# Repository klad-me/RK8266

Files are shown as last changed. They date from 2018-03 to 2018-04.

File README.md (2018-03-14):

# RK8266
Эмулятор Радио-86РК на ESP8266

# Железо
<ul>
    <li>ESP8266 (с флэшкой), например ESP-01: эмулирует процессор и переферию РК86, генерирует видеосигнал стандарта PAL, 
	обрабатывает PS/2 клавиатуру.</li>
    <li>74HC00 (4 элемента 2И-НЕ): используется для генерации видео и синхроимульсов (там простая логика, описана в схеме).</li>
</ul>
В каталоге pcb/ESP-01-LUT есть проект для изготовления платы ЛУТом.<br/>
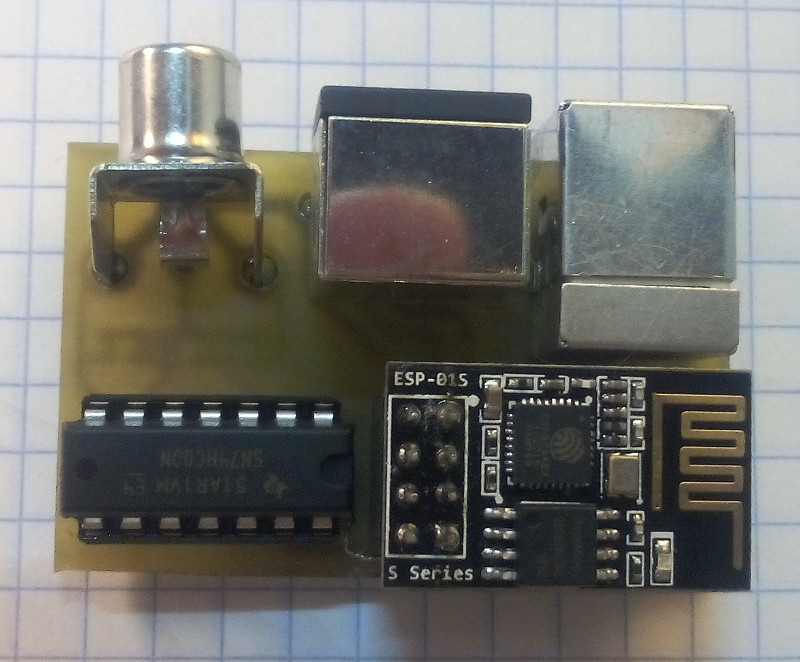
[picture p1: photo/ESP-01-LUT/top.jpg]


# Исходники
Во всех исходниках кодировка КОИ8-Р.<br/>
Проект в стадии разработки.<br/>

# Состав прошивки
Прошивка состоит из 4 частей:
<ul>
    <li>soft/boot-2apps - загрузчик, который переключает между эмулятором и WiFi-прилоежнием.</li>
    <li>soft/EmuAPP - сам эмулятор, работает без SDK полностью из IRAM.</li>
    <li>soft/WiFiAPP - WiFi-приложение для обмена файлами с компьютером.</li>
    <li>soft/WiFiAPP/httpfs - файловая система для HTTP-сервера.</li>
</ul>

# Готовые сборки
Готовые сборки лежат в каталоге builds. Каждый файл имеет имя, соответствующее адресу для прошивки в флэш.<br/>
При прошивке не забывайте правильно указывать размер флэша.<br/>
Пока что все сборки под плату ESP-01-LUT.

# Эмулятор i8080
Используется эмулятор https://github.com/begoon/i8080-core<br/>
При работе ESP8266 на 160МГц и работающем генераторе видеосигнала, частота эмуляции i8080 7.6 .. 8.2 МГц !<br/>

# Переферия
На данный момент реализовано:
<ul>
<li>Процессор (ВМ80) - частота ограничена на 1.78МГц (в будущем, возможно будет турбо-кнопка)</li>
<li>Экран (ВГ75, ИК57) - вывод композитного PAL-сигнала (пока только текст)</li>
<li>Клавиатура (ВВ55) - PS/2 клавиатура с автоматической перекодировкой русских букв и спец.символов</li>
</ul>

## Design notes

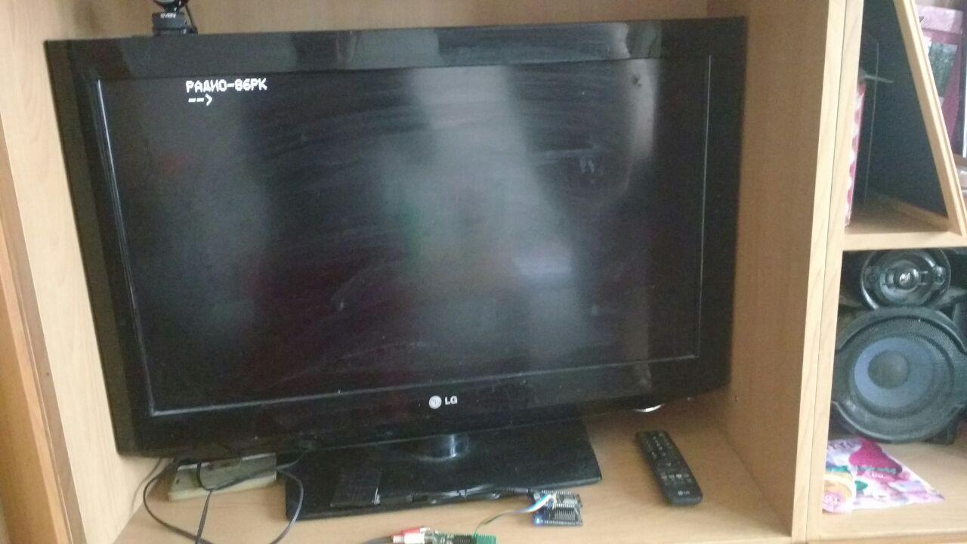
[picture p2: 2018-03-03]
photo/tv.jpg

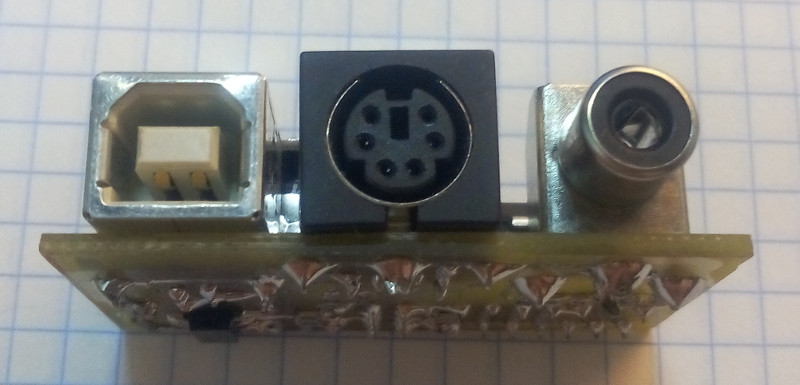
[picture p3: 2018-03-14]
photo/ESP-01-LUT/conn.jpg

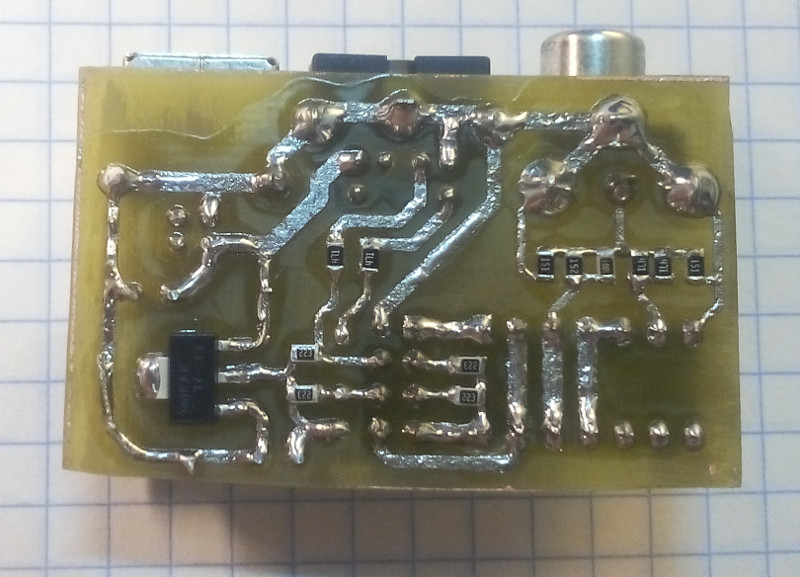
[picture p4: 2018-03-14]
photo/ESP-01-LUT/bottom.jpg

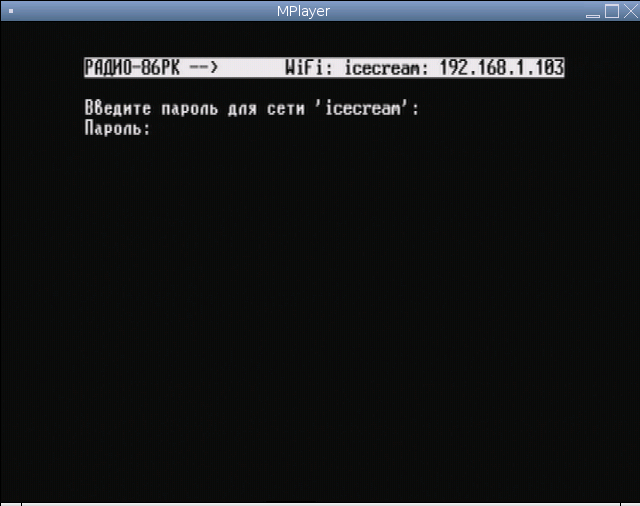
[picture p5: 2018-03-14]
screenshots/rk8266_6.png

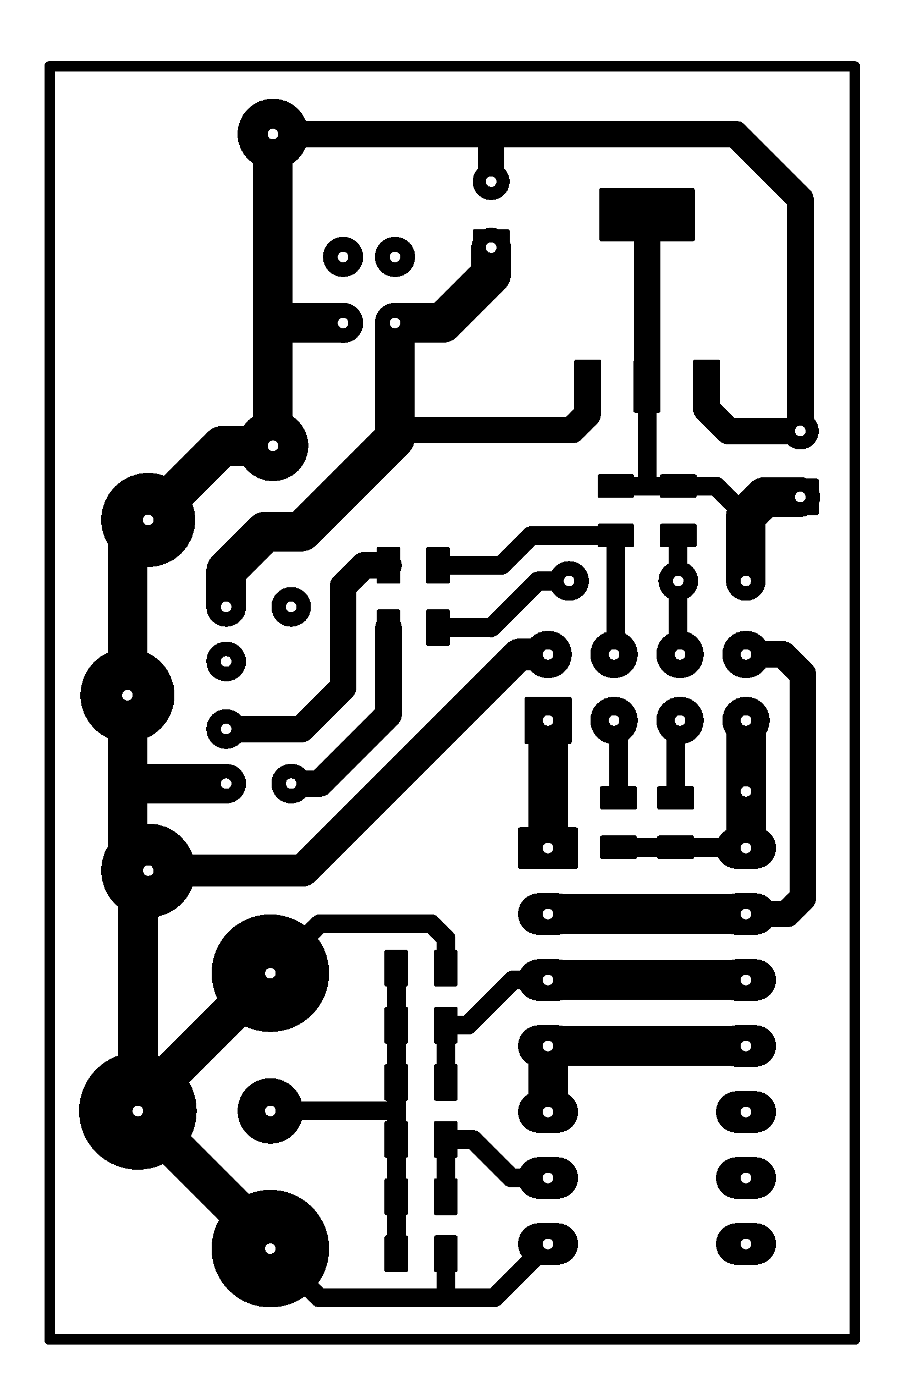
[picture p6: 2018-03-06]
pcb/ESP-01-LUT/pcb/pcb_back.png

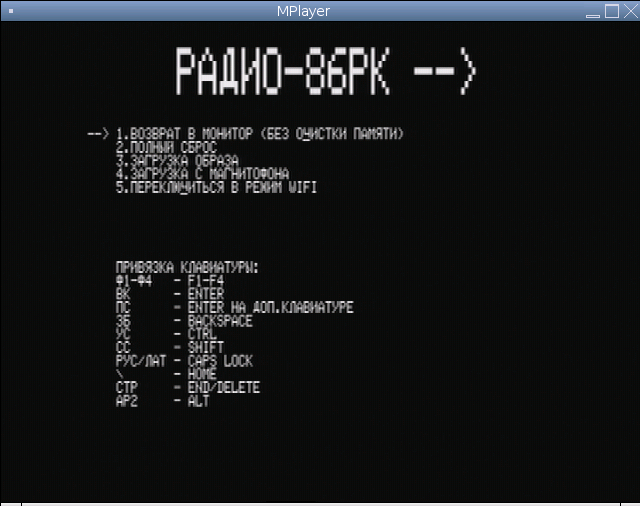
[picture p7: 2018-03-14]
screenshots/rk8266_2.png

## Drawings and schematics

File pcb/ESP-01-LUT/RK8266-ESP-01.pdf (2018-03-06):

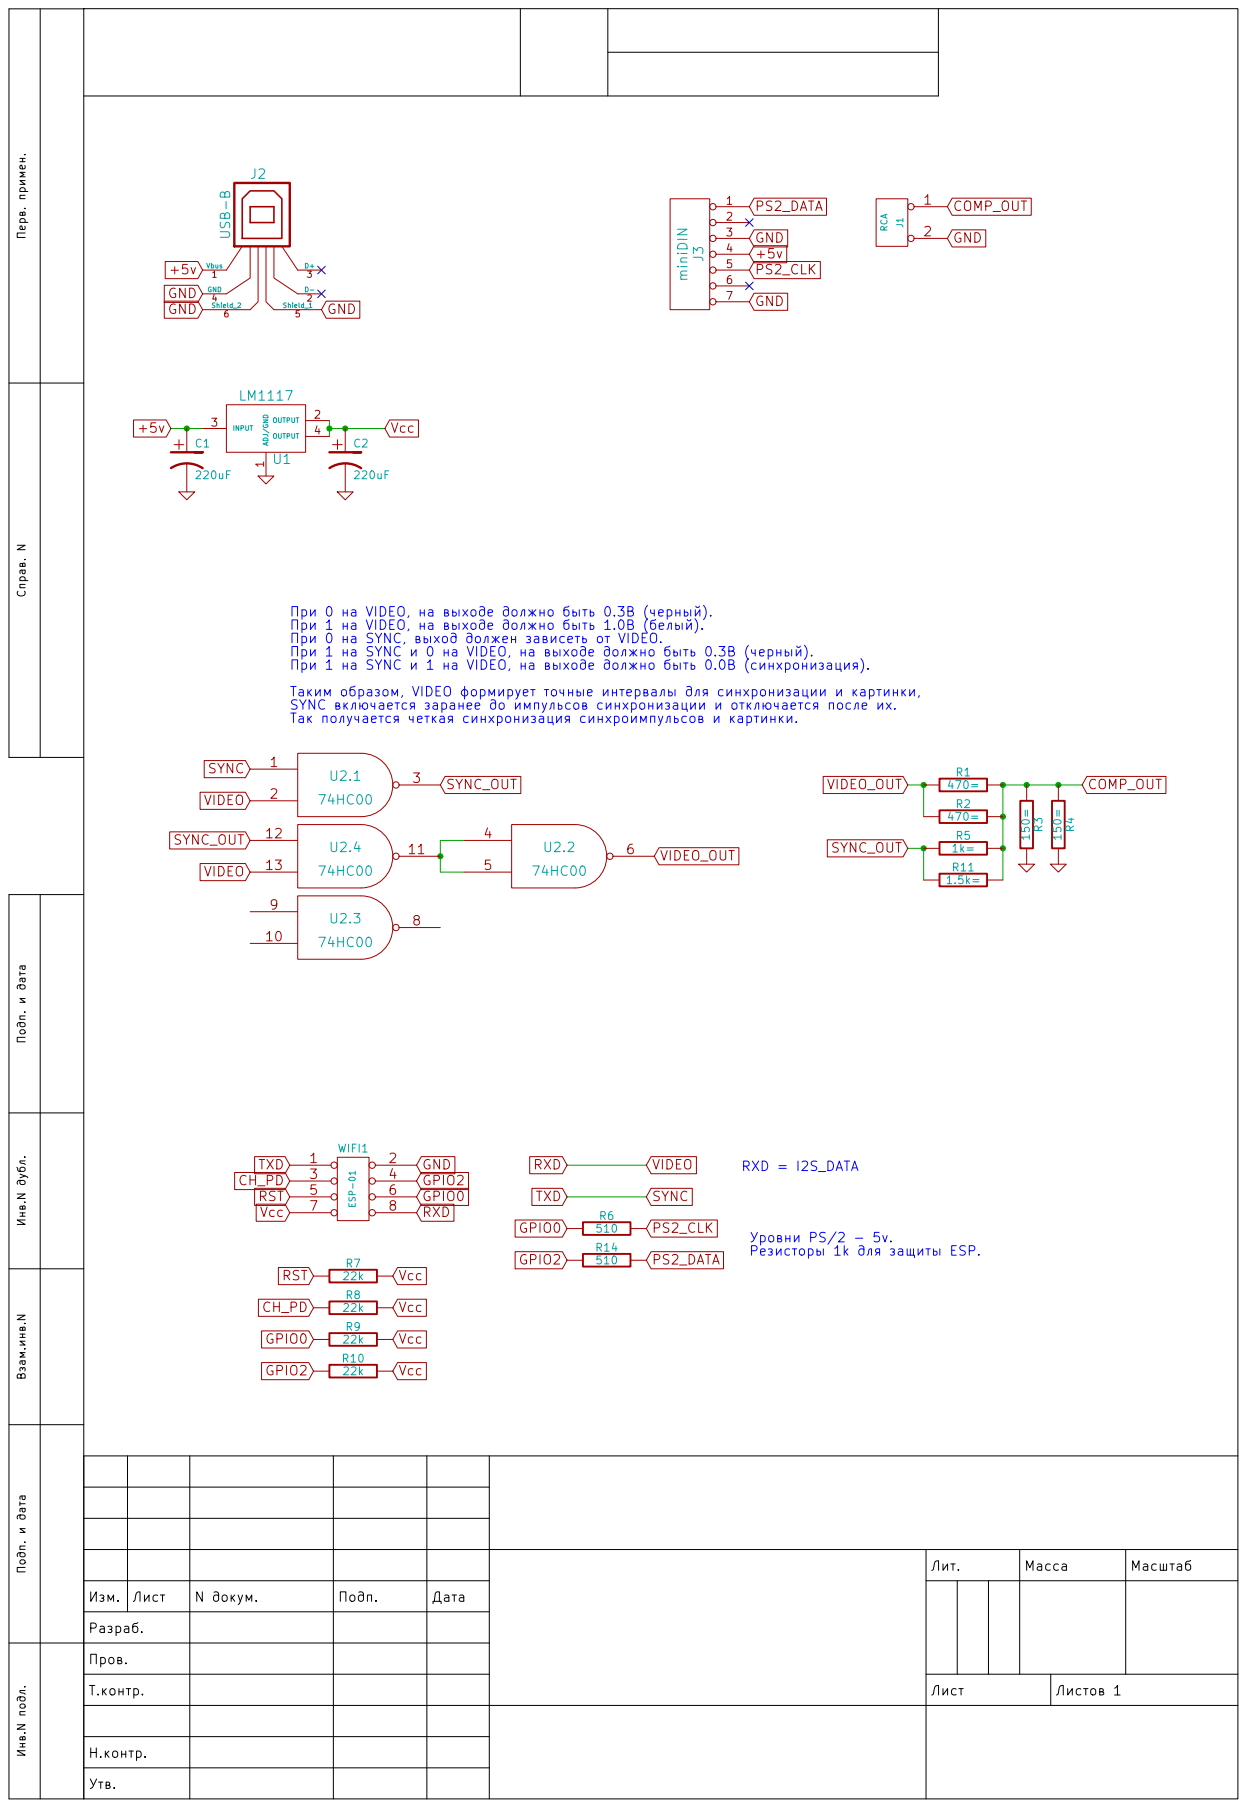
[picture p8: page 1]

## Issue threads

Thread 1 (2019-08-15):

Is it real to add VGA output?

fbezruchko, 2019-08-15:
Its not an issue. But is it real to add VGA output instead composite? Это конечно не issue. Насколько реально добавить поддержку VGA вместо композита? Спасибо!

klad-me, 2021-04-02:
ESP32 has the ability to out VGA.

Closed 2021-04-02.

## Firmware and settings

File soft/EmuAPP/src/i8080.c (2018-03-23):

// Intel 8080 (KR580VM80A) microprocessor core model
//
// Copyright (C) 2012 Alexander Demin <alexander@demin.ws>
//
// Credits
//
// Viacheslav Slavinsky, Vector-06C FPGA Replica
// http://code.google.com/p/vector06cc/
//
// Dmitry Tselikov, Bashrikia-2M and Radio-86RK on Altera DE1
// http://bashkiria-2m.narod.ru/fpga.html
//
// Ian Bartholomew, 8080/8085 CPU Exerciser
// http://www.idb.me.uk/sunhillow/8080.html
//
// Frank Cringle, The original exerciser for the Z80.
//
// Thanks to zx.pk.ru and nedopc.org/forum communities.
//
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
#include "i8080.h"
#include "i8080_hal.h"
#include <inttypes.h>
#include <ets.h>


#define RD_BYTE(addr) i8080_hal_memory_read_byte(addr)
#define RD_WORD(addr) i8080_hal_memory_read_word(addr)

#define WR_BYTE(addr, value) i8080_hal_memory_write_byte(addr, value)
#define WR_WORD(addr, value) i8080_hal_memory_write_word(addr, value)

typedef unsigned char           uns8;
typedef unsigned short          uns16;
typedef unsigned long int       uns32;
typedef signed char             sgn8;
typedef signed short            sgn16;
typedef signed long int         sgn32;

typedef union {
    struct {
        uns8 l, h;
    } b;
    uns16 w;
} reg_pair;

typedef struct {
    uns8 carry_flag;
    uns8 unused1;
    uns8 parity_flag;
    uns8 unused3;
    uns8 half_carry_flag;
    uns8 unused5;
    uns8 zero_flag;
    uns8 sign_flag;
} flag_reg;

struct i8080 {
    flag_reg f;
    reg_pair af, bc, de, hl;
    reg_pair sp, pc;
    uns16 iff;
    uns16 last_pc;
};

#define FLAGS           cpu.f
#define AF              cpu.af.w
#define BC              cpu.bc.w
#define DE              cpu.de.w
#define HL              cpu.hl.w
#define SP              cpu.sp.w
#define PC              cpu.pc.w
#define A               cpu.af.b.h
#define F               cpu.af.b.l
#define B               cpu.bc.b.h
#define C               cpu.bc.b.l
#define D               cpu.de.b.h
#define E               cpu.de.b.l
#define H               cpu.hl.b.h
#define L               cpu.hl.b.l
#define HSP             cpu.sp.b.h
#define LSP             cpu.sp.b.l
#define HPC             cpu.pc.b.h
#define LPC             cpu.pc.b.l
#define IFF             cpu.iff

#define F_CARRY         0x01
#define F_UN1           0x02
#define F_PARITY        0x04
#define F_UN3           0x08
#define F_HCARRY        0x10
#define F_UN5           0x20
#define F_ZERO          0x40
#define F_NEG           0x80

#define C_FLAG          FLAGS.carry_flag
#define P_FLAG          FLAGS.parity_flag
#define H_FLAG          FLAGS.half_carry_flag
#define Z_FLAG          FLAGS.zero_flag
#define S_FLAG          FLAGS.sign_flag
#define UN1_FLAG        FLAGS.unused1
#define UN3_FLAG        FLAGS.unused3
#define UN5_FLAG        FLAGS.unused5

#define SET(flag)       (flag = 1)
#define CLR(flag)       (flag = 0)
#define TST(flag)       (flag)
#define CPL(flag)       (flag = !flag)

#define POP(reg)        { (reg) = RD_WORD(SP); SP += 2; }
#define PUSH(reg)       { SP -= 2; WR_WORD(SP, (reg)); }
#define RET()           { POP(PC); }
#define STC()           { SET(C_FLAG); }
#define CMC()           { CPL(C_FLAG); }

#define INR(reg) \
{                                               \
    ++(reg);                                    \
    S_FLAG = (((reg) & 0x80) != 0);             \
    Z_FLAG = ((reg) == 0);                      \
    H_FLAG = (((reg) & 0x0f) == 0);             \
    P_FLAG = PARITY(reg);                       \
}

#define DCR(reg) \
{                                               \
    --(reg);                                    \
    S_FLAG = (((reg) & 0x80) != 0);             \
    Z_FLAG = ((reg) == 0);                      \
    H_FLAG = !(((reg) & 0x0f) == 0x0f);         \
    P_FLAG = PARITY(reg);                       \
}

#define ADD(val) \
{                                               \
    work16 = (uns16)A + (val);                  \
    index = ((A & 0x88) >> 1) |                 \
            (((val) & 0x88) >> 2) |             \
            ((work16 & 0x88) >> 3);             \
    A = work16 & 0xff;                          \
    S_FLAG = ((A & 0x80) != 0);                 \
    Z_FLAG = (A == 0);                          \
    H_FLAG = half_carry_table[index & 0x7];     \
    P_FLAG = PARITY(A);                         \
    C_FLAG = ((work16 & 0x0100) != 0);          \
}

#define ADC(val) \
{                                               \
    work16 = (uns16)A + (val) + C_FLAG;         \
    index = ((A & 0x88) >> 1) |                 \
            (((val) & 0x88) >> 2) |             \
            ((work16 & 0x88) >> 3);             \
    A = work16 & 0xff;                          \
    S_FLAG = ((A & 0x80) != 0);                 \
    Z_FLAG = (A == 0);                          \
    H_FLAG = half_carry_table[index & 0x7];     \
    P_FLAG = PARITY(A);                         \
    C_FLAG = ((work16 & 0x0100) != 0);          \
}

#define SUB(val) \
{                                                \
    work16 = (uns16)A - (val);                   \
    index = ((A & 0x88) >> 1) |                  \
            (((val) & 0x88) >> 2) |              \
            ((work16 & 0x88) >> 3);              \
    A = work16 & 0xff;                           \
    S_FLAG = ((A & 0x80) != 0);                  \
    Z_FLAG = (A == 0);                           \
    H_FLAG = !sub_half_carry_table[index & 0x7]; \
    P_FLAG = PARITY(A);                          \
    C_FLAG = ((work16 & 0x0100) != 0);           \
}

#define SBB(val) \
{                                                \
    work16 = (uns16)A - (val) - C_FLAG;          \
    index = ((A & 0x88) >> 1) |                  \
            (((val) & 0x88) >> 2) |              \
            ((work16 & 0x88) >> 3);              \
    A = work16 & 0xff;                           \
    S_FLAG = ((A & 0x80) != 0);                  \
    Z_FLAG = (A == 0);                           \
    H_FLAG = !sub_half_carry_table[index & 0x7]; \
    P_FLAG = PARITY(A);                          \
    C_FLAG = ((work16 & 0x0100) != 0);           \
}

#define CMP(val) \
{                                                \
    work16 = (uns16)A - (val);                   \
    index = ((A & 0x88) >> 1) |                  \
            (((val) & 0x88) >> 2) |              \
            ((work16 & 0x88) >> 3);              \
    S_FLAG = ((work16 & 0x80) != 0);             \
    Z_FLAG = ((work16 & 0xff) == 0);             \
    H_FLAG = !sub_half_carry_table[index & 0x7]; \
    C_FLAG = ((work16 & 0x0100) != 0);           \
    P_FLAG = PARITY(work16 & 0xff);              \
}

#define ANA(val) \
{                                               \
    H_FLAG = ((A | val) & 0x08) != 0;           \
    A &= (val);                                 \
    S_FLAG = ((A & 0x80) != 0);                 \
    Z_FLAG = (A == 0);                          \
    P_FLAG = PARITY(A);                         \
    CLR(C_FLAG);                                \
}
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

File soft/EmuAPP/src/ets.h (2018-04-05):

#ifndef ETS_H
#define ETS_H


#include <inttypes.h>

typedef uint8_t bool;
#define false	0
#define true	1
#define FALSE	0
#define TRUE	1


#ifndef NULL
    #define NULL	((void*)0)
#endif


#define AT_IRAM	__attribute__((section(".iram.text")))


typedef enum {
    GPIO_PIN_INTR_DISABLE = 0,
    GPIO_PIN_INTR_POSEDGE = 1,
    GPIO_PIN_INTR_NEGEDGE = 2,
    GPIO_PIN_INTR_ANYEDGE = 3,
    GPIO_PIN_INTR_LOLEVEL = 4,
    GPIO_PIN_INTR_HILEVEL = 5
} GPIO_INT_TYPE;


extern void uart_div_modify(int no, unsigned int freq);

extern void gpio_init(void);
extern void gpio_output_set(uint32_t set_mask,
                     uint32_t clear_mask,
                     uint32_t enable_mask,
                     uint32_t disable_mask);
extern uint32_t gpio_input_get(void);
extern void gpio_pin_intr_state_set(uint32_t i, GPIO_INT_TYPE intr_state);

extern uint32_t SPIRead(uint32_t addr, void *outptr, uint32_t len);
extern uint32_t SPIEraseSector(int);
extern uint32_t SPIWrite(uint32_t addr, const void *inptr, uint32_t len);
extern void SPIUnlock(void);

extern void ets_printf(char*, ...);
extern void ets_install_putc1(void *routine);

extern void ets_delay_us(int);

extern void ets_memset(void*, uint8_t, uint32_t);
extern void ets_memcpy(void*, const void*, uint32_t);
extern int ets_memcmp(const void *s1, const void *s2, uint32_t n);

int ets_sprintf(char *str, const char *format, ...)  __attribute__ ((format (printf, 2, 3)));
extern int ets_strcmp(const char *s1, const char *s2);
extern char *ets_strcpy(char *dest, const char *src);
extern int ets_strlen(const char *s);
extern int ets_strncmp(const char *s1, const char *s2, int len);
extern char *ets_strncpy(char *dest, const char *src, int n);
extern char *ets_strstr(const char *haystack, const char *needle);
extern char *ets_strcat(char *dest, const char *src);
extern char *ets_strchr(const char *s, int c);

extern int ets_get_cpu_frequency(void);
extern void ets_update_cpu_frequency(int freqmhz);

extern void ets_isr_attach(int intr, void *handler, void *arg);
extern void ets_isr_mask(unsigned intr);
extern void ets_isr_unmask(unsigned intr);

extern void rom_i2c_writeReg(uint32_t block, uint32_t host_id, uint32_t reg_add, uint32_t data);
extern void rom_i2c_writeReg_Mask(uint32_t block, uint32_t host_id, uint32_t reg_add, uint32_t Msb, uint32_t Lsb, uint32_t indata);
extern uint8_t rom_i2c_readReg_Mask(uint32_t block, uint32_t host_id, uint32_t reg_add, uint32_t Msb, uint32_t Lsb);
extern uint8_t rom_i2c_readReg(uint32_t block, uint32_t host_id, uint32_t reg_add);

extern void software_reset(int param);


#define BIT(nr)			(1UL << (nr))

#define BIT31	0x80000000
#define BIT30	0x40000000
#define BIT29	0x20000000
#define BIT28	0x10000000
#define BIT27	0x08000000
#define BIT26	0x04000000
#define BIT25	0x02000000
#define BIT24	0x01000000
#define BIT23	0x00800000
#define BIT22	0x00400000
#define BIT21	0x00200000
#define BIT20	0x00100000
#define BIT19	0x00080000
#define BIT18	0x00040000
#define BIT17	0x00020000
#define BIT16	0x00010000
#define BIT15	0x00008000
#define BIT14	0x00004000
#define BIT13	0x00002000
#define BIT12	0x00001000
#define BIT11	0x00000800
#define BIT10	0x00000400
#define BIT9	0x00000200
#define BIT8	0x00000100
#define BIT7	0x00000080
#define BIT6	0x00000040
#define BIT5	0x00000020
#define BIT4	0x00000010
#define BIT3	0x00000008
#define BIT2	0x00000004
#define BIT1	0x00000002
#define BIT0	0x00000001


#define REG_SET_BIT(_r, _b)	(*(volatile uint32_t*)(_r) |= (_b))
#define REG_CLR_BIT(_r, _b)	(*(volatile uint32_t*)(_r) &= ~(_b))


#define ETS_UNCACHED_ADDR(addr)	(addr)
#define READ_PERI_REG(addr) (*((volatile uint32_t *)ETS_UNCACHED_ADDR(addr)))
#define WRITE_PERI_REG(addr, val) (*((volatile uint32_t *)ETS_UNCACHED_ADDR(addr))) = (uint32_t)(val)
#define CLEAR_PERI_REG_MASK(reg, mask) WRITE_PERI_REG((reg), (READ_PERI_REG(reg)&(~(mask))))
#define SET_PERI_REG_MASK(reg, mask)   WRITE_PERI_REG((reg), (READ_PERI_REG(reg)|(mask)))
#define GET_PERI_REG_BITS(reg, hipos,lowpos)      ((READ_PERI_REG(reg)>>(lowpos))&((1<<((hipos)-(lowpos)+1))-1))
#define SET_PERI_REG_BITS(reg,bit_map,value,shift) (WRITE_PERI_REG((reg),(READ_PERI_REG(reg)&(~((bit_map)<<(shift))))|((value)<<(shift)) ))


#define ETS_INTR_ENABLE(inum) \
    ets_isr_unmask((1<<inum))

#define ETS_INTR_DISABLE(inum) \
    ets_isr_mask((1<<inum))

#define ETS_GPIO_INTR_ATTACH(func, arg) \
    ets_isr_attach(ETS_GPIO_INUM, (func), (void *)(arg))

#define ETS_GPIO_INTR_ENABLE() \
    ETS_INTR_ENABLE(ETS_GPIO_INUM)


#define PERIPHS_GPIO_BASEADDR		0x60000300
#define GPIO_REG_READ(reg)		READ_PERI_REG(PERIPHS_GPIO_BASEADDR + reg)
#define GPIO_REG_WRITE(reg, val)	WRITE_PERI_REG(PERIPHS_GPIO_BASEADDR + reg, val)
#define GPIO_STATUS_ADDRESS		0x1c
#define GPIO_STATUS_W1TC_ADDRESS	0x24
#define ETS_GPIO_INUM			4


#endif

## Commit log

2018-03-03 Обновление README
2018-03-03 Первый импорт исходников.
2018-03-04 Доделан драйвер PS/2.
2018-03-04 Сделана поддержка PS/2 клавиатуры.
2018-03-06 Сборка проекта по ESP-01, плата в каталоге pcb/.
    [RK86.brd, RK86.sch]
2018-03-06 Фото новой платы на ESP-01.
2018-03-07 Версия без использования SDK (работает полностью из IRAM), делаю поддержку магнитофона.
2018-03-08 Сделано меню со сбросом + много правок кода.
2018-03-14 Большая переделка проекта
2018-03-14 Правка README
2018-03-14 Добавлены скриншоты.
2018-03-15 Исправлена ошибка при чтении файлов программ.
2018-03-18 - Оптимизация ОЗУ - Режим "Турбо", переключается ScrollLock - Работает магнитофон
2018-03-23 Исправлена работа клавиатур USB/PS2. Загружаемый генератор по адресу 0xF800 (только запись). Обновление прошивки по воздуху (HTTP PUT /firmware.bin).
    [i8080.c]
2018-03-25 Переделана работа ВГ75, поддержка аттрибутов и псевдографики. Картинку можно двигать Win+Курсор. Переделана Web-страница, доступно обновление прошивки. 0x00000.bin - файл для прошивки программатором 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
2018-03-31 Улучшена поддержка ВГ75, добавлена эмуляция звука на GPIO14.
2018-04-05 Переделай файловый менеджер. Сделана сортировка файлов по имени. Перезапись существующих файлов. Отображение версии прошивки. Убраны тормоза клавиатуры (при быстром нажатии нескольких кнопок они теря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
2018-04-05 Исправлена ошибка в загрузчике (не работало обновление по воздуху).
    [ets.h]
2018-04-06 Исправлена ошибка, из-за которой портился Flash.
2018-04-06 Скачивание и закачивание образа FS Автоматическая перезагрузка после обновления прошивки Более правильное управлние частотй эмуляцией (считаем такты ПДП и притормаживаем проц).
2018-04-07 Добавлена справка по кнопке Menu.
2018-05-03 Изменена привязка кнопок управления эмуляцией. 4 шрифта с переключением аттрибутами GPA. Дополнительные 8кб ОЗУ. Дополнительные 6кб ПЗУ. Возможность загружать образы ПЗУ по WiFi. Немного доработана с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
2018-05-03 Бинарная сборка #23.

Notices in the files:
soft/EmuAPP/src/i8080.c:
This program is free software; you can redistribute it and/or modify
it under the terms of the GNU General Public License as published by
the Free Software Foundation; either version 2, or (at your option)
